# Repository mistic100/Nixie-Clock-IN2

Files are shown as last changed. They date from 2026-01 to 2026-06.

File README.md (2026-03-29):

# Nixie Clock IN-2

Check out my other projects:
- [Nixie Clock IN14](https://github.com/mistic100/Nixie-Clock-IN14)
- [Nixie Clock IN12](https://github.com/mistic100/Nixie-Clock-IN12)
- [IV-27 VFD Clock](https://github.com/mistic100/IV-27-Clock)

This is a Nixie Clock using small [IN-2 tubes](https://www.tube-tester.com/sites/nixie/data/I/IN-2/in-2.htm) and a 16x9 LED matrix. It was mostly inspired by this 3D model [80s Alarm Clock by Tom Seddon](https://sketchfab.com/3d-models/80s-alarm-clock-36aaecc458bc4e3ea907cdb9d538c9f1).



[More photos](https://photos.strangeplanet.fr/index.php?/category/268-horloge_nixie_in_2_mars_2026)

### Key features

- 3 buttons and 1 rotary encoder
- Zigbee connectivity
  - receive date-time
  - receive weather
  - send room temperature and humidity
  - can be toggled on/off
  - 3 generic buttons send click, double click, long click events
- small LED matrix with multiple screens
  - scrolling date
  - temperature
  - falling sand animation
  - Game of Life animation
  - fire animation
  - rain animation
- possibility to use a DS3231 RTC module (routed on the PCB but not available in current firmware)

### BOM

- ESP32-C6 SuperMini
- Adafruit Charlieplexed 16x9 LED matrix + IS31FL3731 driver
- 4x IN-2 Nixie tubes
- 2x INS-1 Nixie indicators
- Microchip HV5222 serial-to-parallel converter
- Adafruit 4 channels TTL level-shifter
- 4x APA106 5mm adressable LEDs
- BME280 ambient sensor
- EC11 rotary encoder
- 3x 6x6x4.3mm push buttons
- MPSA42 high voltage NPN transistor
- USB-C connector
- resistors, capacitors, diodes...

### Schematics



### PCB



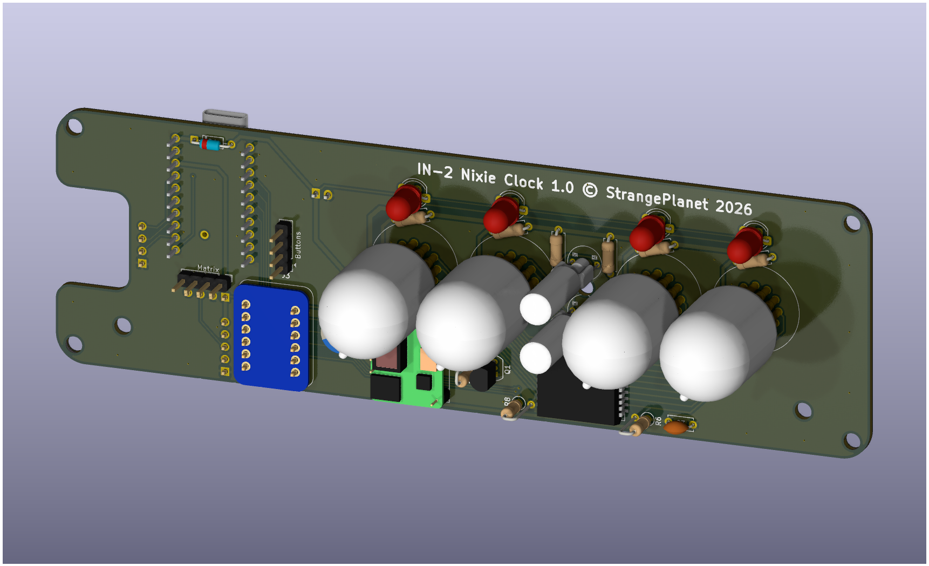
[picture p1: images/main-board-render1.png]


### Case

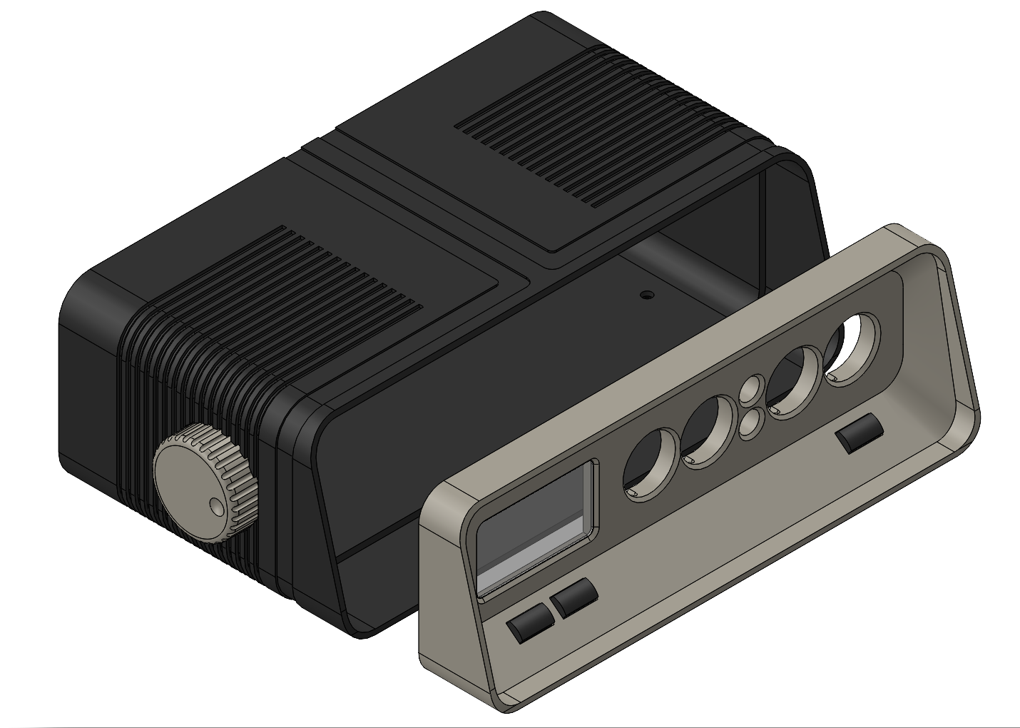
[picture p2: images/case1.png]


## License

The Arduino code, the KiCad design and SolidWorks files are distributed under the Creative Commons 3.0 BY-SA license.

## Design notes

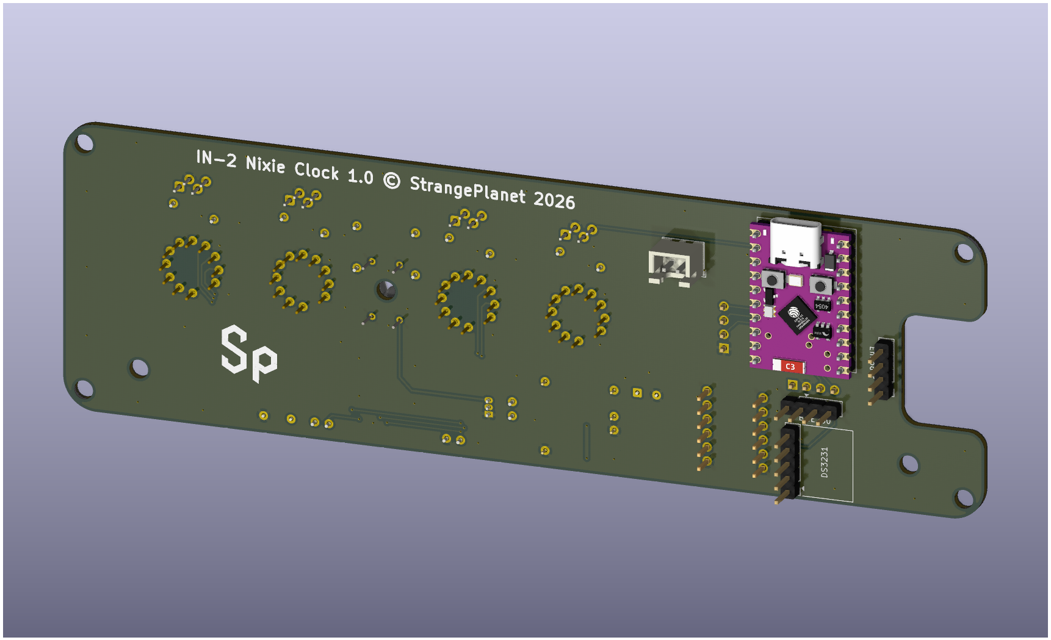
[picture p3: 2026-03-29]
images/main-board-render2.png

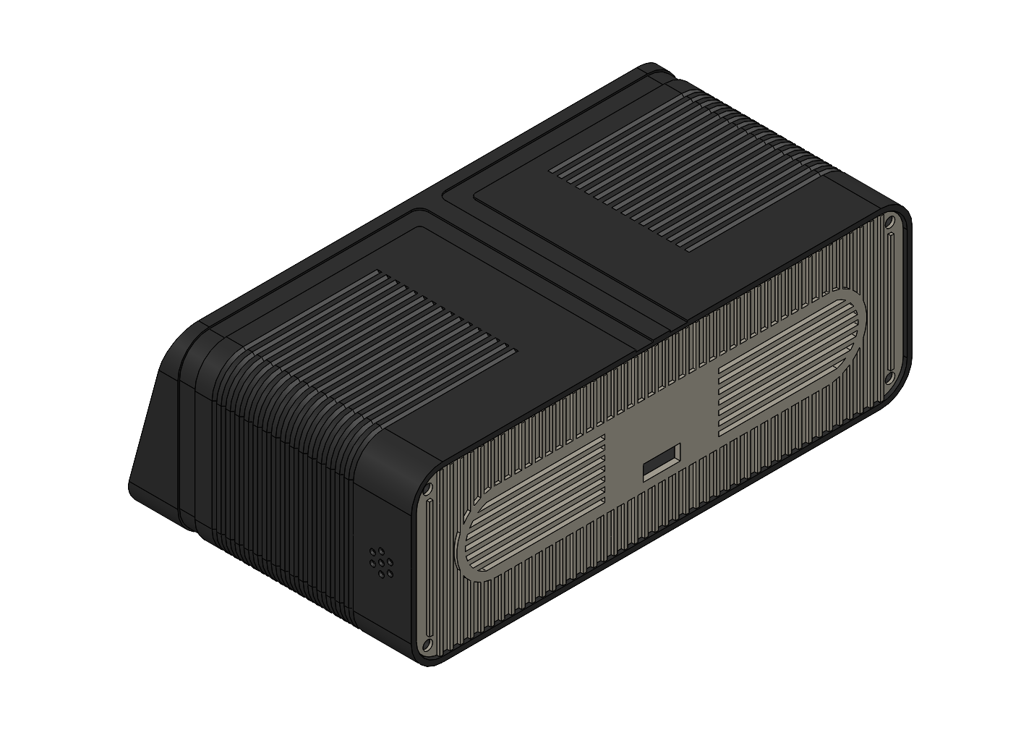
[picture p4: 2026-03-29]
images/case2.png

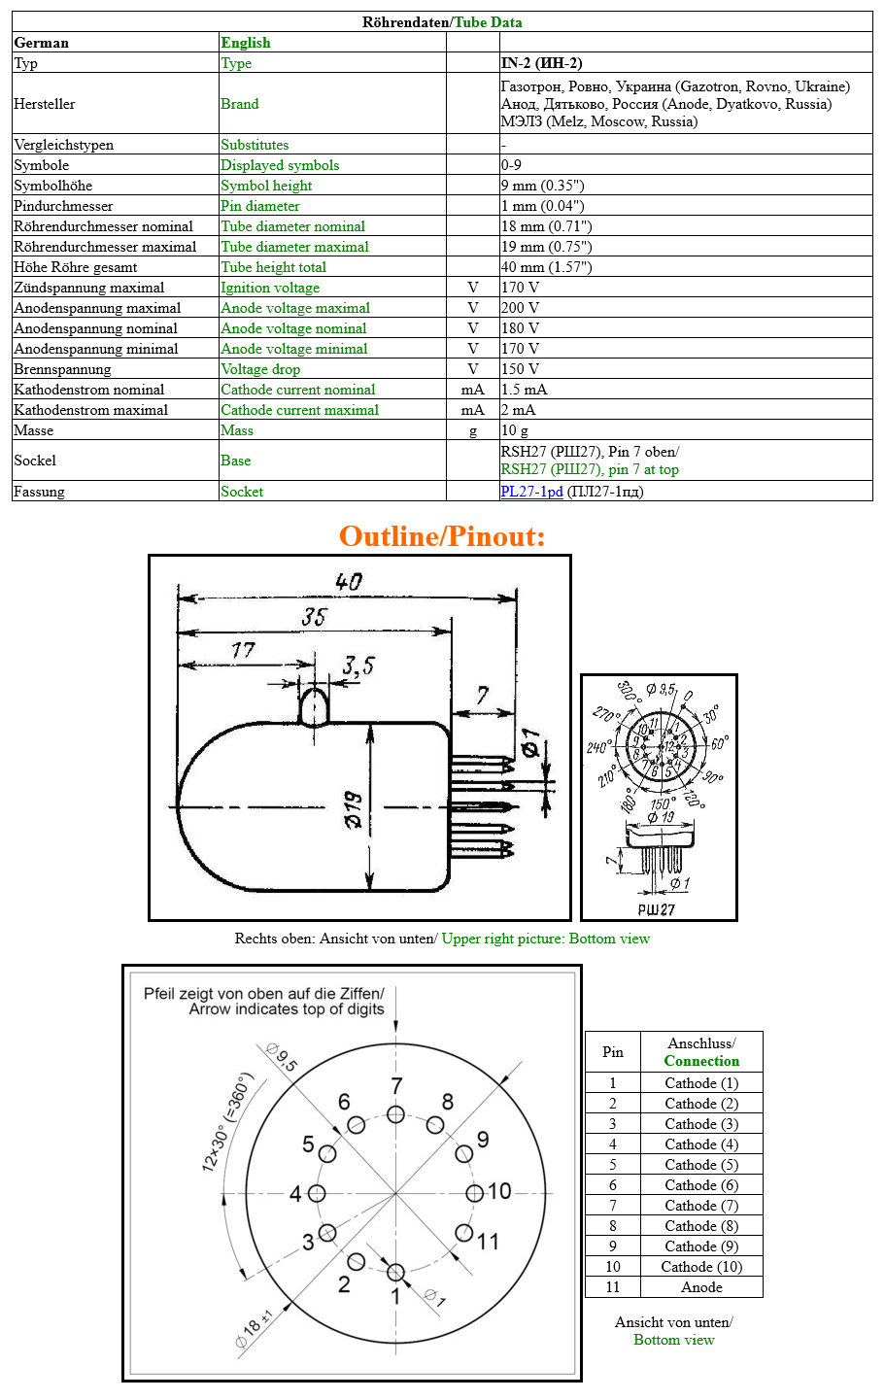
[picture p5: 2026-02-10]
datasheets/IN-2.jpg

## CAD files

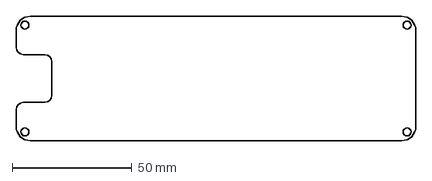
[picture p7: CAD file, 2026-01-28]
main-board/pcb.DXF
167.0 x 52.0 mm

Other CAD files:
3d model/_in-2 nixie.SLDASM
3d model/Adafruit Charliplexed Matrix 9x16/Adafruit Charliplexed Matrix 9x16.SLDASM
3d model/nixie pins.SLDASM
3d model/Adafruit Charliplexed Matrix 9x16/board.SLDPRT
3d model/ins1 support.SLDPRT
buttons-board/buttons-board.step
main-board/in-2-nixie.step
3d model/Adafruit Charliplexed Matrix 9x16/GNL-0603xx.SLDPRT
3d model/foot.SLDPRT
3d model/ribbon.SLDPRT
3d model/box.SLDPRT
3d model/EC11 Rotary Encoder 15mm.SLDPRT
3d model/Neonwork Nixie Power Supply.SLDPRT
3d model/pcb-bracket.SLDPRT
3d model/BME280.SLDPRT
3d model/DS3231.SLDPRT
3d model/Adafruit Charlieplexed PWM Driver Breakout.SLDPRT
3d model/IN-2 Nixie Tube.SLDPRT
3d model/INS1.SLDPRT
3d model/m3-spacer-20mm.SLDPRT
3d model/nixie pin.SLDPRT
3d model/pcb.SLDPRT
3d model/type c jack connector.SLDPRT

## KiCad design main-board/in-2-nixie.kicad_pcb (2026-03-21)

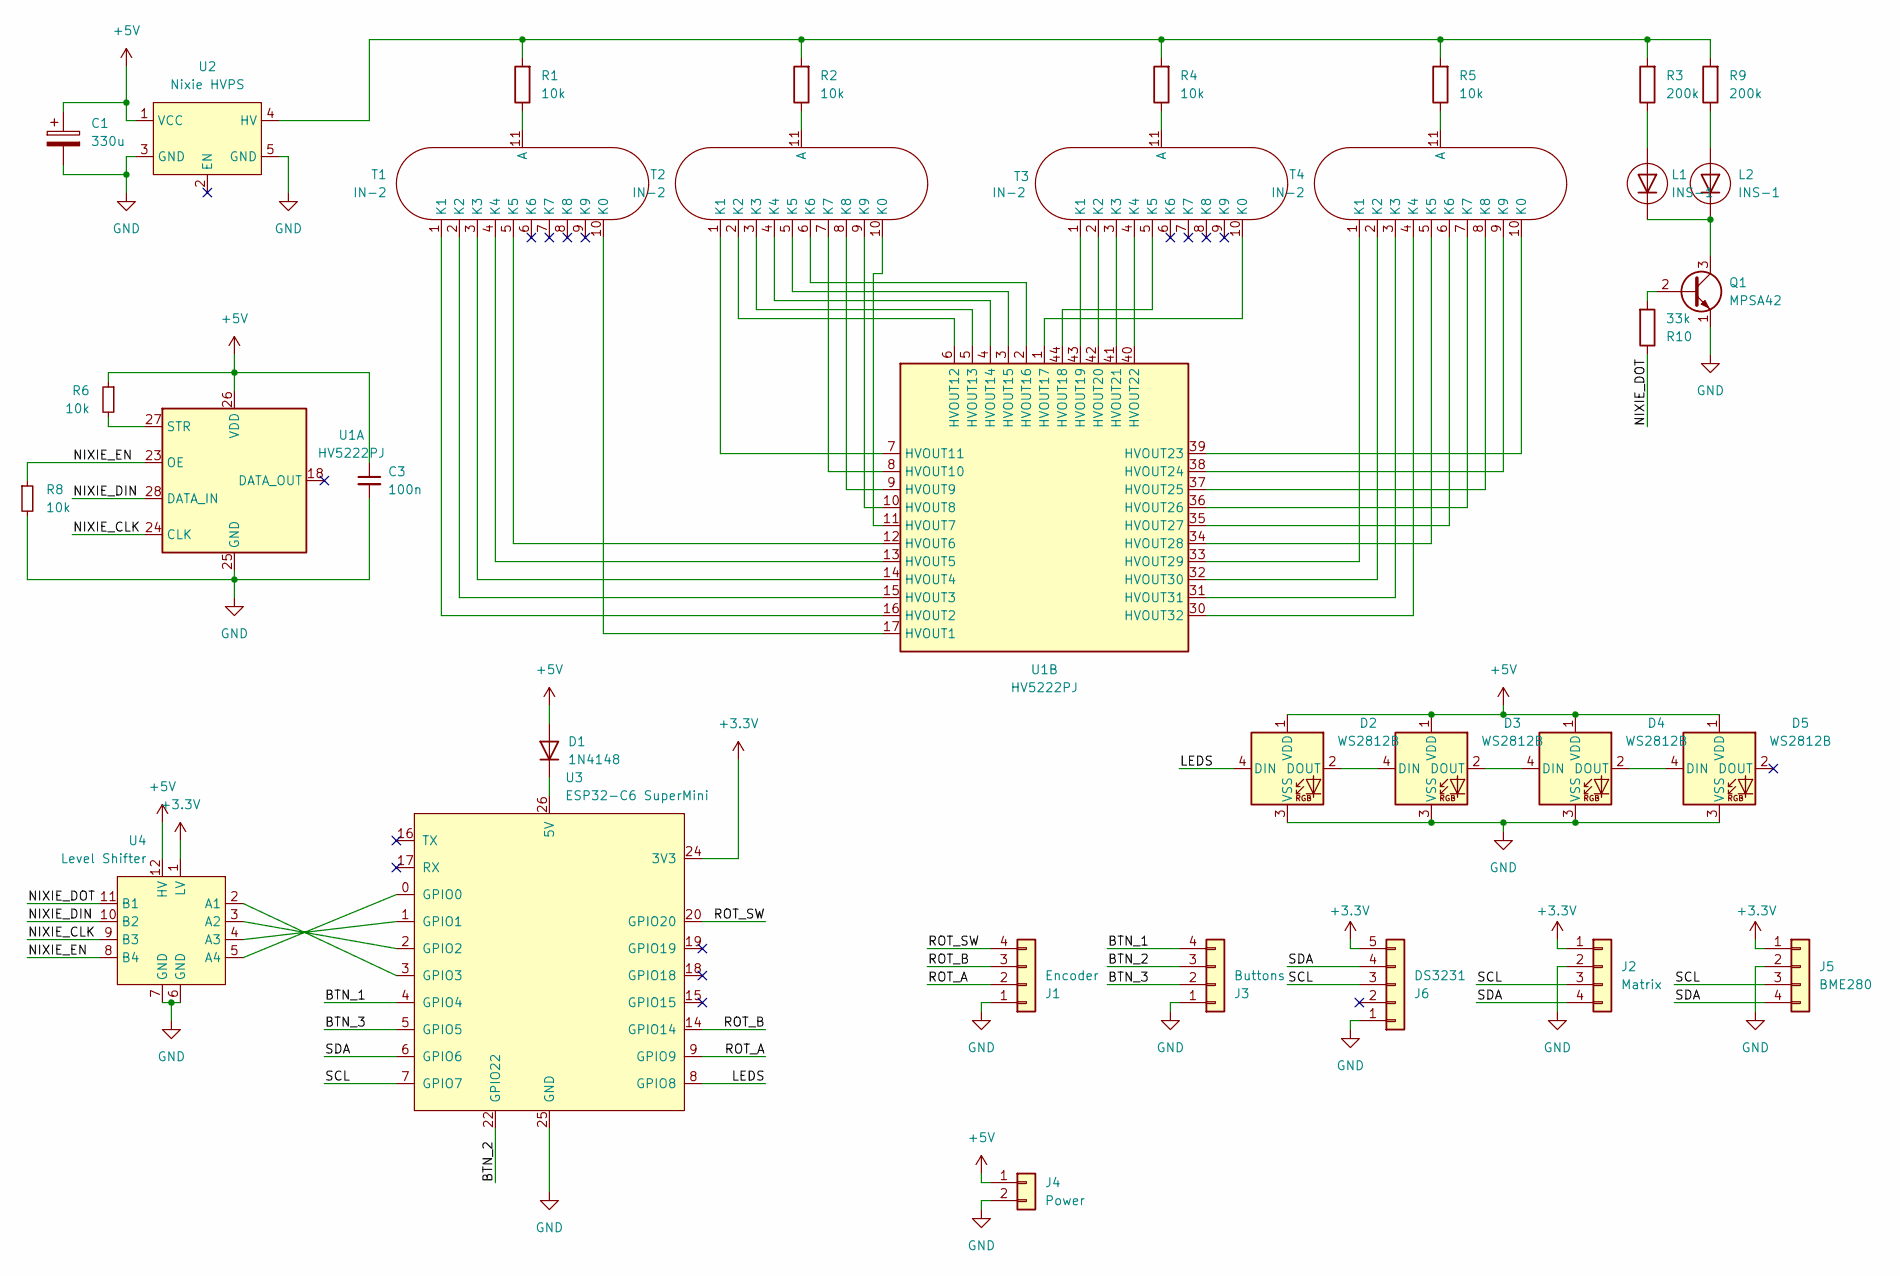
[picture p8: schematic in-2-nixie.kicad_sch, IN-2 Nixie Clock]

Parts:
C1: 330u; CP_Radial_D8.0mm_P3.50mm
C3: 100n; C_Disc_D5.0mm_W2.5mm_P5.00mm
D1: 1N4148; D_DO-35_SOD27_P7.62mm_Horizontal
D2, D3, D4, D5: WS2812B; APA106_D5-Staggered_Pins
J1: Encoder; PinHeader_1x04_P2.54mm_Vertical
J2: Matrix; PinHeader_1x04_P2.54mm_Vertical
J3: Buttons; PinHeader_1x04_P2.54mm_Vertical
J4: Power; JST_XH_B2B-XH-A_1x02_P2.50mm_Vertical
J5: BME280; PinHeader_1x04_P2.54mm_Vertical
J6: DS3231; PinHeader_1x05_P2.54mm_Vertical
L1, L2: INS-1; INS-1 Nixie Tube
Q1: MPSA42; TO-92_Inline
R1, R2, R4, R5: 10k; R_Axial_DIN0207_L6.3mm_D2.5mm_P7.62mm_Horizontal
R3, R9: 200k; R_Axial_DIN0207_L6.3mm_D2.5mm_P7.62mm_Horizontal
R6, R8: 10k; R_Axial_DIN0207_L6.3mm_D2.5mm_P2.54mm_Vertical
R10: 33k; R_Axial_DIN0207_L6.3mm_D2.5mm_P2.54mm_Vertical
T1, T2, T3, T4: IN-2; IN-2 Nixie Tube (w. pins)
U1: HV5222PJ; PLCC-44 LongPads
U2: Nixie HVPS; Neonwork Nixie Power Supply
U3: ESP32-C6 SuperMini
U4: Level Shifter; Adafruit Level Shifter

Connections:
+3.3V: J2.1, J5.1, J6.5, U3.24 (3V3), U4.1 (LV)
+5V: C1.1, C3.1, D1.2 (A), D2.1 (VDD), D3.1 (VDD), D4.1 (VDD), D5.1 (VDD), J4.1, R6.1, U1.26 (VDD), U2.1 (VCC), U4.12 (HV)
/BTN_1: J3.4, U3.4 (GPIO4)
/BTN_2: J3.3, U3.22 (GPIO22)
/BTN_3: J3.2, U3.5 (GPIO5)
/LEDS: D2.4 (DIN), U3.8 (GPIO8)
/NIXIE_CLK: U1.24 (CLK), U4.9 (B3)
/NIXIE_DIN: U1.28 (DATA_IN), U4.10 (B2)
/NIXIE_DOT: R10.1, U4.11 (B1)
/NIXIE_EN: R8.1, U1.23 (OE), U4.8 (B4)
/ROT_A: J1.2, U3.9 (GPIO9)
/ROT_B: J1.3, U3.14 (GPIO14)
/ROT_SW: J1.4, U3.20 (GPIO20)
/SCL: J2.3, J5.3, J6.3, U3.7 (GPIO7)
/SDA: J2.4, J5.4, J6.4, U3.6 (GPIO6)
GND: C1.2, C3.2, D2.3 (VSS), D3.3 (VSS), D4.3 (VSS), D5.3 (VSS), J1.1, J2.2, J3.1, J4.2, J5.2, J6.1, Q1.1 (E), R8.2, U1.25 (GND), U2.3 (GND), U2.5 (GND), U3.25 (GND), U4.6 (GND), U4.7 (GND)
unnamed: D1.1 (K), U3.26 (5V)
unnamed: D2.2 (DOUT), D3.4 (DIN)
unnamed: D3.2 (DOUT), D4.4 (DIN)
unnamed: D4.2 (DOUT), D5.4 (DIN)
unnamed: L1.2 (A), R3.1
unnamed: L1.1 (K), L2.1 (K), Q1.3 (C)
unnamed: L2.2 (A), R9.1
unnamed: Q1.2 (B), R10.2
unnamed: R1.1, T1.11 (A)
unnamed: T1.10 (K0), U1.17 (HVOUT1)
unnamed: T1.1 (K1), U1.16 (HVOUT2)
unnamed: T1.2 (K2), U1.15 (HVOUT3)
unnamed: T1.3 (K3), U1.14 (HVOUT4)
unnamed: T1.4 (K4), U1.13 (HVOUT5)
unnamed: T1.5 (K5), U1.12 (HVOUT6)
unnamed: R2.1, T2.11 (A)
unnamed: T2.10 (K0), U1.11 (HVOUT7)
unnamed: T2.1 (K1), U1.7 (HVOUT11)
unnamed: T2.2 (K2), U1.6 (HVOUT12)
unnamed: T2.3 (K3), U1.5 (HVOUT13)
unnamed: T2.4 (K4), U1.4 (HVOUT14)
unnamed: T2.5 (K5), U1.3 (HVOUT15)
unnamed: T2.6 (K6), U1.2 (HVOUT16)
unnamed: T2.7 (K7), U1.8 (HVOUT10)
unnamed: T2.8 (K8), U1.9 (HVOUT9)
unnamed: T2.9 (K9), U1.10 (HVOUT8)
unnamed: R4.1, T3.11 (A)
unnamed: T3.10 (K0), U1.1 (HVOUT17)
unnamed: T3.1 (K1), U1.43 (HVOUT19)
unnamed: T3.2 (K2), U1.42 (HVOUT20)
unnamed: T3.3 (K3), U1.41 (HVOUT21)
unnamed: T3.4 (K4), U1.40 (HVOUT22)
unnamed: T3.5 (K5), U1.44 (HVOUT18)
unnamed: R5.1, T4.11 (A)
unnamed: T4.10 (K0), U1.39 (HVOUT23)
unnamed: T4.1 (K1), U1.33 (HVOUT29)
unnamed: T4.2 (K2), U1.32 (HVOUT30)
unnamed: T4.3 (K3), U1.31 (HVOUT31)
unnamed: T4.4 (K4), U1.30 (HVOUT32)
unnamed: T4.5 (K5), U1.34 (HVOUT28)
unnamed: T4.6 (K6), U1.35 (HVOUT27)
unnamed: T4.7 (K7), U1.36 (HVOUT26)
unnamed: T4.8 (K8), U1.37 (HVOUT25)
unnamed: T4.9 (K9), U1.38 (HVOUT24)
unnamed: R6.2, U1.27 (STR)
unnamed: R1.2, R2.2, R3.2, R4.2, R5.2, R9.2, U2.4 (HV)
unnamed: U3.0 (GPIO0), U4.5 (A4)
unnamed: U3.1 (GPIO1), U4.4 (A3)
unnamed: U3.2 (GPIO2), U4.3 (A2)
unnamed: U3.3 (GPIO3), U4.2 (A1)

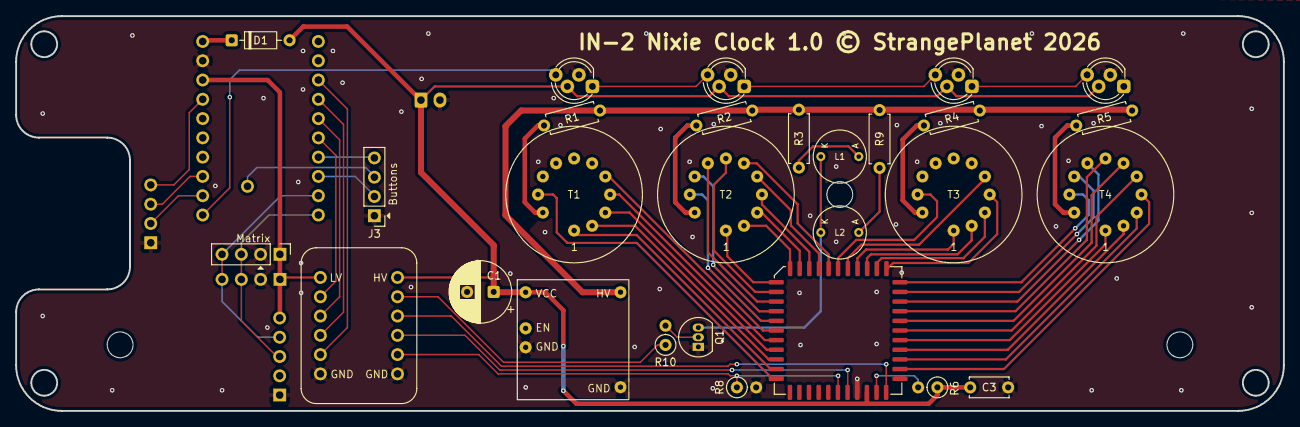
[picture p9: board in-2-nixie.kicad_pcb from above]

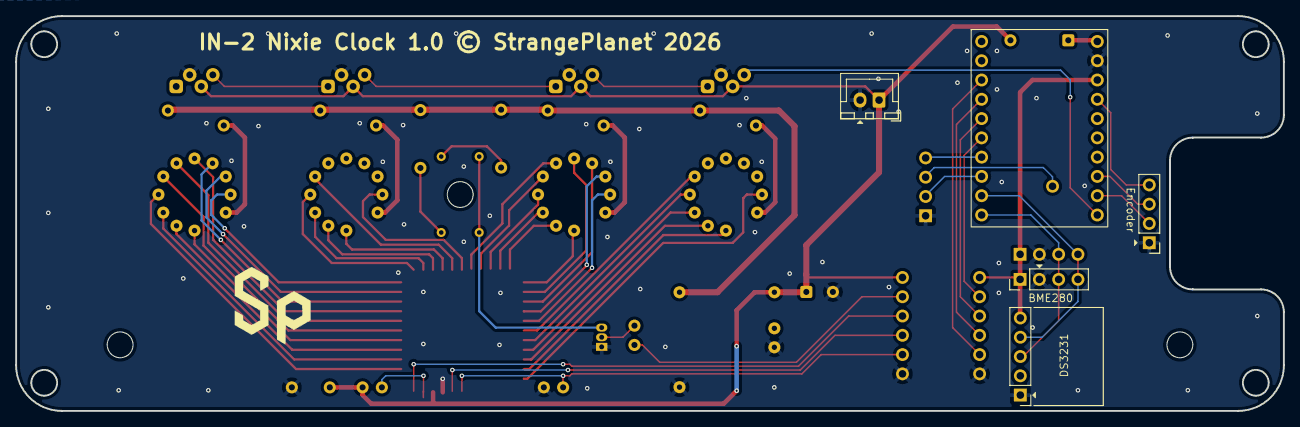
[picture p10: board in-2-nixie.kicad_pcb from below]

Board: 2 copper layers, 167.0 x 52.0 mm, 33 parts (5 on the bottom side), 66 nets.

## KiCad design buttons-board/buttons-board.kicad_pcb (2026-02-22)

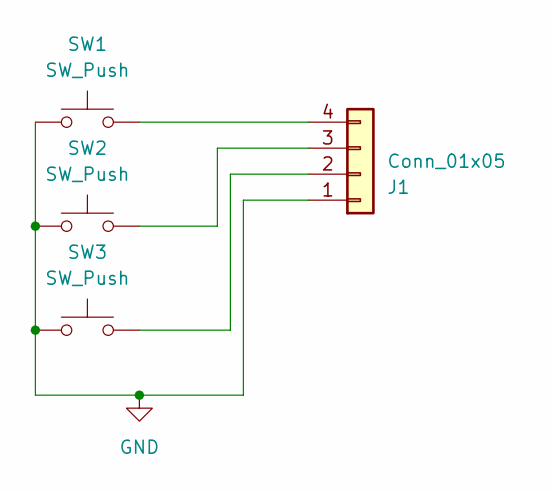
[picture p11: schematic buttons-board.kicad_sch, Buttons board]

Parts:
J1: Conn_01x05; PinHeader_1x04_P2.54mm_Horizontal
SW1, SW2, SW3: SW_Push; SW_PUSH_6mm_H4.3mm

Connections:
GND: J1.1, SW1.1, SW2.1, SW3.1
unnamed: J1.2, SW3.2
unnamed: J1.3, SW2.2
unnamed: J1.4, SW1.2

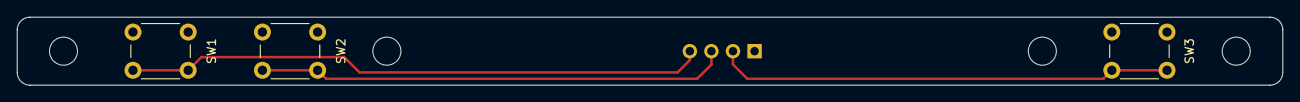
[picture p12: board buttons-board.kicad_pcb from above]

Board: 2 copper layers, 149.0 x 8.0 mm, 4 parts (1 on the bottom side), 4 nets.

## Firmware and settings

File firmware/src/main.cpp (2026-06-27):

#include <Arduino.h>
#include <Wire.h>
#include <Button2.h>
#include "constants.hpp"
#include "RotaryEncoder.hpp"
#include "TimeKeeper.hpp"
#include "ZigbeeController.hpp"
#include "BmeDriver.hpp"
#include "Settings.hpp"
#include "MatrixDriver.hpp"
#include "NixieDriver.hpp"
#include "LedDriver.hpp"

#define TAG_MAIN "MAIN"

RotaryHandler encoder(ENCODER_A, ENCODER_B);
Button2 encoderButton;
Button2 button1;
Button2 button2;
Button2 button3;

void IRAM_ATTR encoderISR()
{
    encoder.tick();
}

void setup()
{
    Serial.begin(115200);

    setenv("TZ", TIMEZONE, 1);
    tzset();

    settings.begin();

    encoderButton.setLongClickTime(LONG_CLICK_MS);
    button1.setLongClickTime(LONG_CLICK_MS);
    button2.setLongClickTime(LONG_CLICK_MS);
    button3.setLongClickTime(LONG_CLICK_MS);

    encoderButton.setDoubleClickTime(DOUBLE_CLICK_MS);
    button1.setDoubleClickTime(DOUBLE_CLICK_MS);
    button2.setDoubleClickTime(DOUBLE_CLICK_MS);
    button3.setDoubleClickTime(DOUBLE_CLICK_MS);

    encoder.begin(encoderISR);
    encoderButton.begin(ENCODER_SW);
    button1.begin(BTN_1);
    button2.begin(BTN_2);
    button3.begin(BTN_3);

    encoder.onUp([]()
                 { 
        ESP_LOGI(TAG_MAIN, "Encoder up");
        nixieDriver.setTempDisplay();
        matrix.nextMode(); });

    encoder.onDown([]()
                   { 
        ESP_LOGI(TAG_MAIN, "Encoder down");
        nixieDriver.setTempDisplay();
        matrix.prevMode(); });

    encoderButton.setClickHandler([](Button2 &btn)
                                  { 
        ESP_LOGI(TAG_MAIN, "Encoder click");
        zigbeeCtrl.toggleMainSwitch(); });

    button1.setClickHandler([](Button2 &btn)
                            { 
        ESP_LOGI(TAG_MAIN, "Btn 1 click");
        zigbeeCtrl.sendBtnEvent(1, CLICK); });

    button1.setDoubleClickHandler([](Button2 &btn)
                                  { 
        ESP_LOGI(TAG_MAIN, "Btn 1 double click");
        zigbeeCtrl.sendBtnEvent(1, DOUBLE_CLICK); });

    button1.setLongClickDetectedHandler([](Button2 &btn)
                                        { 
        ESP_LOGI(TAG_MAIN, "Btn 1 long click");
        zigbeeCtrl.sendBtnEvent(1, LONG_CLICK); });

    button2.setClickHandler([](Button2 &btn)
                            { 
        ESP_LOGI(TAG_MAIN, "Btn 2 click");
        zigbeeCtrl.sendBtnEvent(2, CLICK); });

    button2.setDoubleClickHandler([](Button2 &btn)
                                  { 
        ESP_LOGI(TAG_MAIN, "Btn 2 double click");
        zigbeeCtrl.sendBtnEvent(2, DOUBLE_CLICK); });

    button2.setLongClickDetectedHandler([](Button2 &btn)
                                        { 
        ESP_LOGI(TAG_MAIN, "Btn 2 long click");
        zigbeeCtrl.sendBtnEvent(2, LONG_CLICK); });

    button3.setClickHandler([](Button2 &btn)
                            { 
        ESP_LOGI(TAG_MAIN, "Btn 3 click");
        zigbeeCtrl.sendBtnEvent(3, CLICK); });

    button3.setDoubleClickHandler([](Button2 &btn)
                                  { 
        ESP_LOGI(TAG_MAIN, "Btn 3 double click");
        zigbeeCtrl.sendBtnEvent(3, DOUBLE_CLICK); });

    button3.setLongClickDetectedHandler([](Button2 &btn)
                                        { 
        ESP_LOGI(TAG_MAIN, "Btn 3 long click");
        zigbeeCtrl.sendBtnEvent(3, LONG_CLICK); });

    zigbeeCtrl.onMainSwitchChange([](bool state)
                                  {
        ESP_LOGI(TAG_MAIN, "Main state %d", state);
        leds.setState(state);
        matrix.setState(state);
        nixieDriver.setState(state);
        settings.setState(state); });

    zigbeeCtrl.onLedColorChange([](bool state, uint8_t hue, uint8_t saturation, uint8_t value)
                                { leds.setColor(hue, saturation, value); });

    zigbeeCtrl.onWeather([](u8_t weatherCode)
                         { matrix.setWeather(weatherCode); });

    zigbeeCtrl.onTempOffset([](int16_t offset)
                            { bme.setOffset(offset / 100.0); });

    timeKeeper.onMinute([]()
                        {
        matrix.updateTime();
        nixieDriver.update(); });

    bme.onData([](bme_data_t data)
               {
        zigbeeCtrl.setTempAndHumidity(data.temp, data.humi);
        matrix.setTemp(data.temp); });

    Wire.begin(SDA1, SCL1);
    matrix.begin();
    bme.begin();
    leds.begin();
    nixieDriver.begin();
    zigbeeCtrl.begin();

    delay(2000);

    ESP_LOGI(TAG_MAIN, "Ready");

    zigbeeCtrl.requestTime();
    matrix.updateTime();
    nixieDriver.update();
}

void loop()
{
    encoderButton.loop();
    button1.loop();
    button2.loop();
    button3.loop();

    timeKeeper.loop();
    zigbeeCtrl.loop();
    bme.loop();
    matrix.loop();
    leds.loop();
    nixieDriver.loop();

    EVERY_N_MINUTES(10)
    {
        zigbeeCtrl.requestTime();
    }
}

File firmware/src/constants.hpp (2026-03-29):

#pragma once

// zigbee configuration
#define ZIGBEE_MANUFACTURER "StrangePlanet"
#define ZIGBEE_MODEL "IN-2-Clock"
#define ZIGBEE_ENDPOINT_MAIN 1
#define ZIGBEE_ENDPOINT_BME280 2
#define ZIGBEE_ENDPOINT_LEDS 3
#define ZIGBEE_ENDPOINT_CUSTOM 10
#define ZIGBEE_CUSTOM_CLUSTER_ID 0xFF01
#define ZIGBEE_ATTR_ACTION_ID 0x0000
#define ZIGBEE_ATTR_WEATHER_ID 0x0001
#define ZIGBEE_ATTR_TEMP_OFFSET 0x0002

// screen matrix configuration
#define SCREEN_ROTATION 0
#define SCREEN_WIDTH 16
#define SCREEN_HEIGHT 9
#define SCREEN_BRIGHTNESS 20

// nixie driver configuration
#define DRIVER_DIN 2
#define DRIVER_CLK 1
#define DRIVER_OE 0

#define DOTS 3

#define ANTI_POISONING_INTERVAL_S 20 * 60
#define ANTI_POISONING_CYCLES 100

#define TEMP_DISPLAY_DURATION_S 30

// buttons configuration
#define ENCODER_A 9
#define ENCODER_B 14
#define ENCODER_SW 20

#define BTN_1 4
#define BTN_2 22
#define BTN_3 5

#define DOUBLE_CLICK_MS 300
#define LONG_CLICK_MS 500

// bme280 configuration
#define TEMP_UPDATE_INTERVAL_S 60

// leds configuration
#define LEDS_PIN RGB_BUILTIN
#define NUM_LEDS 6 // built-in + 4 + 1 for safety
#define LEDS_ORDER LED_COLOR_ORDER_RGB

// datetime configuration
#define TIMEZONE "CET-1CEST,M3.5.0,M10.5.0/3" // https://github.com/esp8266/Arduino/blob/master/cores/esp8266/TZ.h
#define LOCALIZED_DATE

#ifdef LOCALIZED_DATE
const char* DAY_NAMES[7] = {
    "DIM",
    "LUN",
    "MAR",
    "MER",
    "JEU",
    "VEN",
    "SAM"
};

const char* MONTH_NAMES[12] = {
    "JAN",
    "FEV",
    "MAR",
    "AVR",
    "MAI",
    "JUN",
    "JUI",
    "AOU",
    "SEP",
    "OCT",
    "NOV",
    "DEC"
};
#endif

// nixie driver configuration
const uint8_t PIN_H10[6] = {
    1,
    2,
    3,
    4,
    5,
    6};

const uint8_t PIN_H[10] = {
    7,
    11,
    12,
    13,
    14,
    15,
    16,
    10,
    9,
    8};

const uint8_t PIN_M10[6] = {
    17,
    19,
    20,
    21,
    22,
    18};

const uint8_t PIN_M[10] = {
    23,
    29,
    30,
    31,
    32,
    28,
    27,
    26,
    25,
    24};

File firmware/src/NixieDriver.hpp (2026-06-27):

#pragma once

#include <Arduino.h>
#include <FastLED.h>
#include "constants.hpp"
#include "TimeKeeper.hpp"

#define TAG_NIXIE "NIXIE"

class NixieDriver
{
private:
    byte _data[32];
    bool _state = true;
    volatile bool _changed = false;
    bool _dots = false;
    u8_t _antipoisoning_timer = 0;
    volatile u8_t _temp_display_timer = 0;

public:
    void begin()
    {
        pinMode(DRIVER_DIN, OUTPUT);
        pinMode(DRIVER_CLK, OUTPUT);
        pinMode(DRIVER_OE, OUTPUT);
        pinMode(DOTS, OUTPUT);

        digitalWrite(DRIVER_DIN, LOW);
        digitalWrite(DRIVER_CLK, LOW);
        digitalWrite(DRIVER_OE, LOW);
        digitalWrite(DOTS, LOW);
    }

    void loop()
    {
        EVERY_N_SECONDS(1)
        {
            if (_state || _temp_display_timer)
            {
                _dots = !_dots;
                digitalWrite(DOTS, _dots);
            }
            if (_temp_display_timer)
            {
                _temp_display_timer = _temp_display_timer - 1;
                if (!_temp_display_timer)
                {
                    ESP_LOGI(TAG_NIXIE, "Temp display end");
                    setState(false);
                }
            }
        }

        EVERY_N_SECONDS(ANTI_POISONING_INTERVAL_S)
        {
            if (_state && !_temp_display_timer)
            {
                ESP_LOGI(TAG_NIXIE, "Start anti poisoning");
                _antipoisoning_timer = ANTI_POISONING_CYCLES;
            }
        }

        EVERY_N_MILLIS(10)
        {
            if (_antipoisoning_timer)
            {
                runAntipoisoning();
            }
        }

        if (_changed && !_antipoisoning_timer)
        {
            _changed = false;
            
            if (_state || _temp_display_timer)
            {
                auto timeinfo = timeKeeper.getTime();

                u8_t h10 = timeinfo->tm_hour / 10;
                u8_t h = timeinfo->tm_hour % 10;
                u8_t m10 = timeinfo->tm_min / 10;
                u8_t m = timeinfo->tm_min % 10;

                showDigits(h10, h, m10, m);
                digitalWrite(DRIVER_OE, HIGH);
            }
            else
            {
                digitalWrite(DRIVER_OE, LOW);
                digitalWrite(DOTS, LOW);
            }
        }
    }

    void setState(bool state)
    {
        _state = state;
        _temp_display_timer = 0;
        _changed = true;
    }

    void update()
    {
        if (_state)
        {
            _changed = true;
        }
    }

    void setTempDisplay()
    {
        if (!_state)
        {
            ESP_LOGI(TAG_NIXIE, "Start temp display for %ds", TEMP_DISPLAY_DURATION_S);
            _temp_display_timer = TEMP_DISPLAY_DURATION_S;
            _changed = true;
        }
    }

private:
    void showDigits(u8_t h10, u8_t h, u8_t m10, u8_t m)
    {
        ESP_LOGI(TAG_NIXIE, "Show: %d%d:%d%d", h10, h, m10, m);

        std::fill(_data, _data + 32, 0);

        if (h10 < 6) _data[PIN_H10[h10] - 1] = 1;
        if (h < 10) _data[PIN_H[h] - 1] = 1;
        if (m10 < 6) _data[PIN_M10[m10] - 1] = 1;
        if (m < 10) _data[PIN_M[m] - 1] = 1;

        for (s8_t i = 31; i >= 0; i--)
        {
            digitalWrite(DRIVER_DIN, _data[i]);
            digitalWrite(DRIVER_CLK, HIGH);
            digitalWrite(DRIVER_CLK, LOW);
        }
    }

    void runAntipoisoning()
    {
        // loop each digit 0 to 9
        showDigits(_antipoisoning_timer % 10, _antipoisoning_timer % 10, _antipoisoning_timer % 10, _antipoisoning_timer % 10);

        _antipoisoning_timer--;
        if (!_antipoisoning_timer)
        {
            ESP_LOGI(TAG_NIXIE, "Anti poisoning end");
            _changed = true;
        }
    }
};

NixieDriver nixieDriver;

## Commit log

2026-01-29 ground plane
    [buttons-board.kicad_pcb, buttons-board.kicad_sch]
2026-02-21 update model
    [6X6X4.3_BUTTON.SLDPRT, BME280.SLDPRT, EC11 Rotary Encoder 15mm.SLDPRT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]
2026-02-22 pcb final
    [buttons-board.kicad_pcb, buttons-board.kicad_sch, in-2-nixie.kicad_pcb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]
2026-03-21 fix encoder routing
    [in-2-nixie.kicad_pcb, in-2-nixie.kicad_sch]
2026-03-23 fix nixie driver
2026-03-26 Fix time init, ZB led control, ZB temp offset
    [CustomZigbeeEP.hpp, NixieDriver.hpp]
2026-03-29 Remove OTA partition
    [partitions.csv]
